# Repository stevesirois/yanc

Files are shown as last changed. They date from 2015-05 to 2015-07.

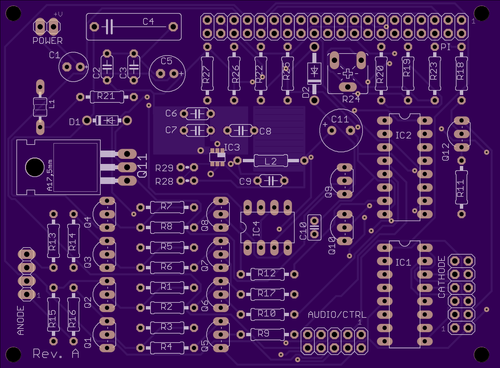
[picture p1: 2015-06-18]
eagle-stuffs/nixie-driver.png

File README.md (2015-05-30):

# YANC
Y.A.N.C. - Yet Another Nixie Clock

This project is the software part of a larger project that include nixie tube clock with no physical controls but only "web" access.

The physical construction will be publish on Instructables (http://www.instructables.com/)

The project is two parts:

Physical part - Nixie Clock

- 4 nixie tubes (IN-14) display
- Raspberry PI Model A+ (256MB) for main controller
- Custom nixie driver circuit and audio ouput (PCB)
- MP3 Playback for alarm
- Sound activated display (extented life of tubes)

Software part - Clock control and remote app

- Controler daemon for clock hardware control (Python)
- REST Server to interact with external world (look mom, no button!)
- IOS App to "talk" to the clock (Swift)

Simply put, this clock will look great, will sync itself on the Net and get it's alarms from my Google Calendar! :-)

More details coming...

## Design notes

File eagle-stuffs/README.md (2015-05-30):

# Eagle 7.2 files
The .sch and .brd files are Eagle CAD schematic and PCB design files.

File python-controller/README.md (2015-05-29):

# Raspberry PI Controller

Python server controlling display, audio & REST server

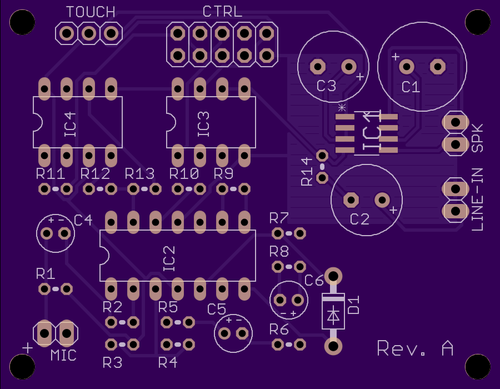
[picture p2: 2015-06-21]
eagle-stuffs/audio.png

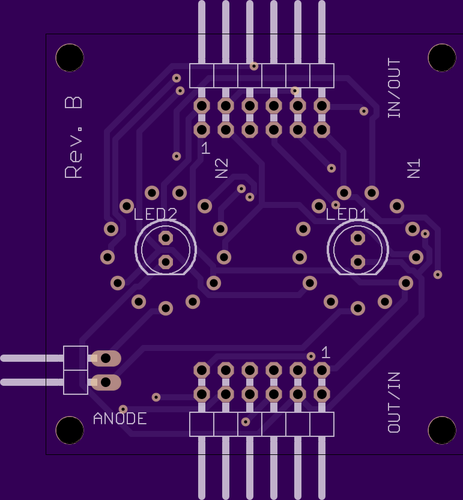
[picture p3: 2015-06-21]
eagle-stuffs/lamp_board_simple.png

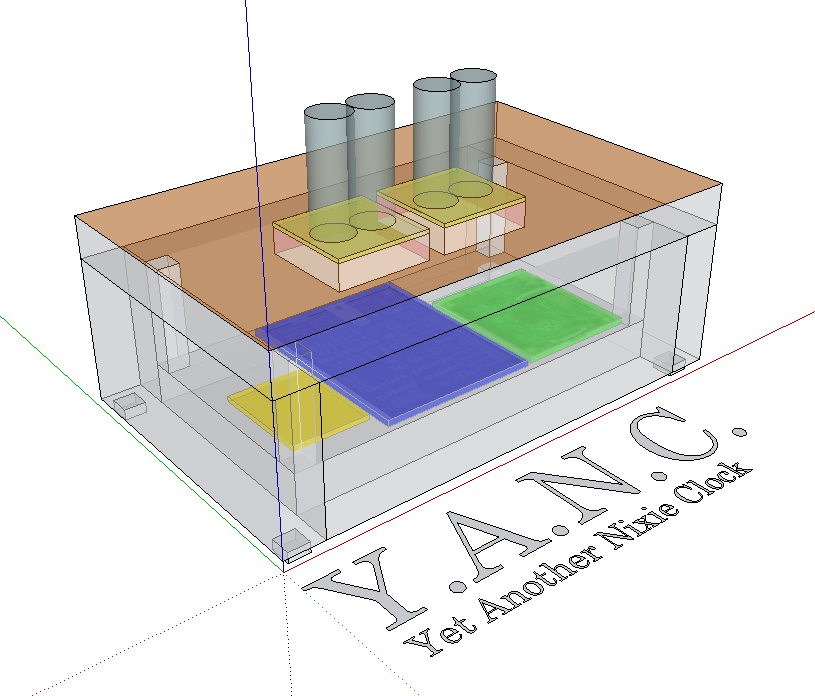
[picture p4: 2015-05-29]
Sketchup-3D/Snapshot.png

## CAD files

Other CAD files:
Sketchup-3D/Nixie clock-full.skp

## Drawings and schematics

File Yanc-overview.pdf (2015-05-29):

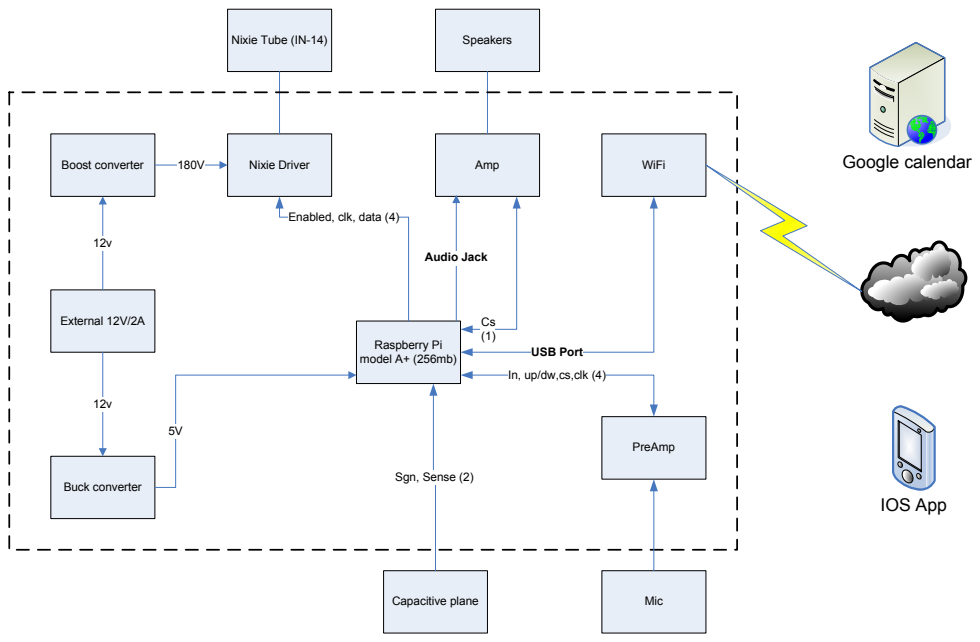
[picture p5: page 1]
Raspberry Pi model A+ (256mb); Boost converter; Nixie Driver; External 12V/2A; Capacitive plane; Sgn, Sense (2); WiFi; USB Port; Amp; Speakers; Audio Jack; Buck converter; Google calendar; Mic; PreAmp; IOS App

Nixie Tube (IN-14)

Enabled, clk, data (4)

In, up/dw,cs,clk (4)

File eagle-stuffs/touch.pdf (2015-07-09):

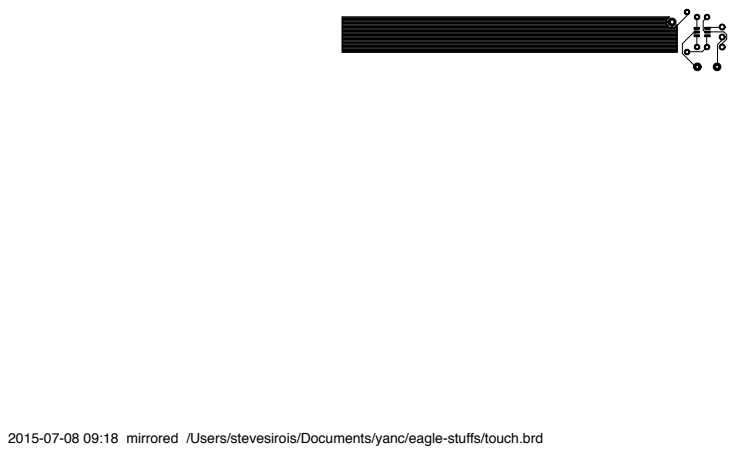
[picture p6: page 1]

2015-07-08 09:18 mirrored /Users/stevesirois/Documents/yanc/eagle-stuffs/touch.brd

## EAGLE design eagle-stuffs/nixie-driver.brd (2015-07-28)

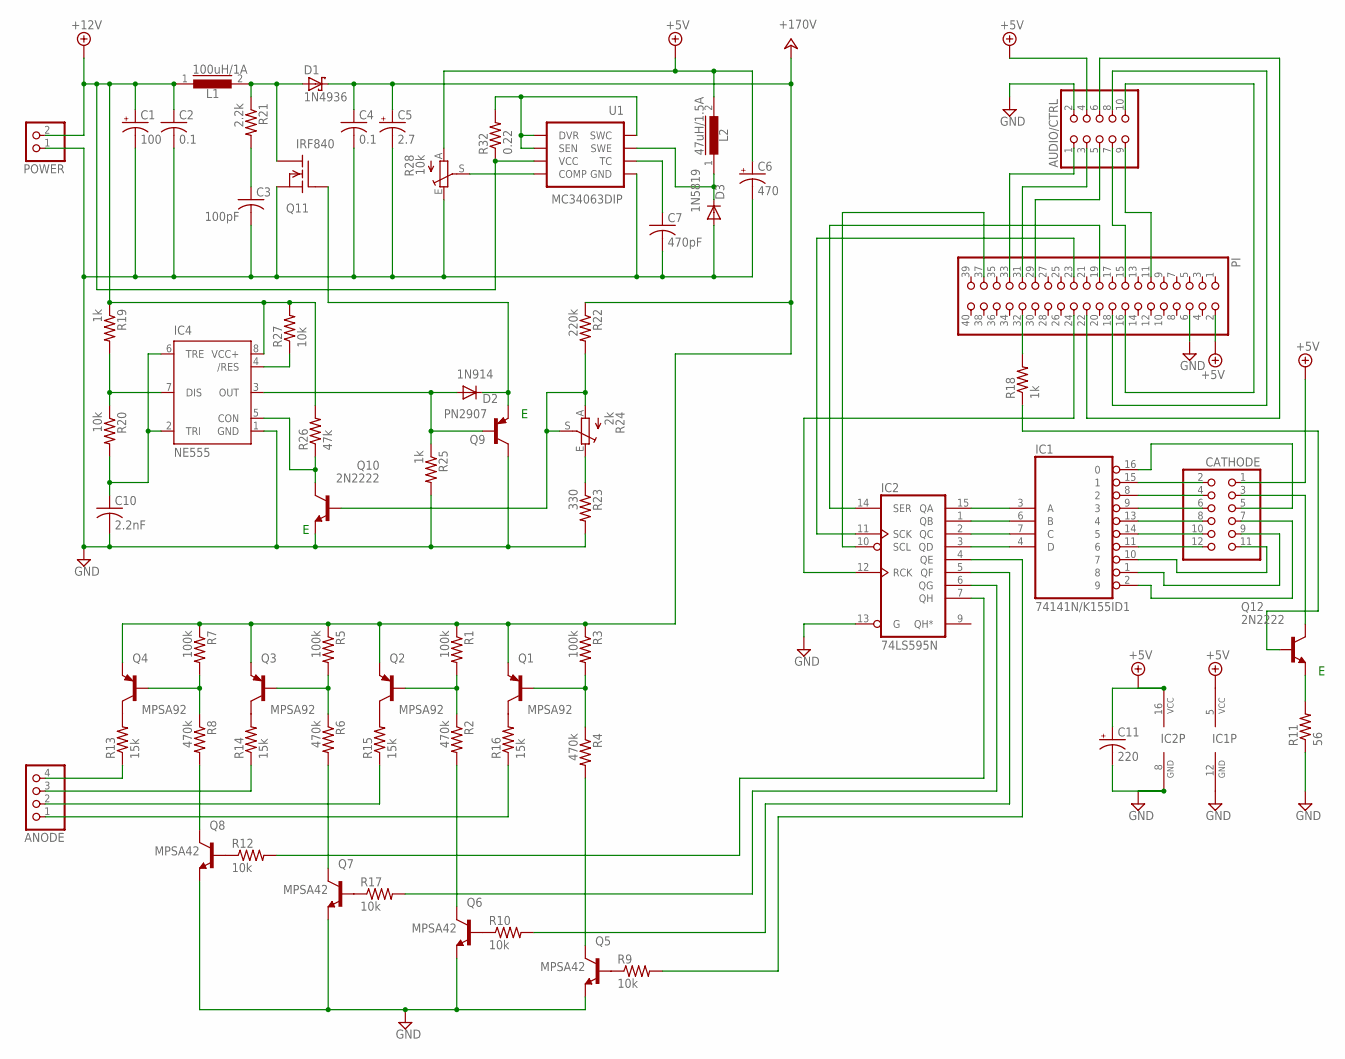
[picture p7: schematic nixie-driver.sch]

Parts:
ANODE: PINHD-1X4; 1X04
AUDIO/CTRL: PINHD-2X5; 2X05
C1: 100; E2,5-6E
C2: 0.1; C050-024X044
C3: 100pF; C050-024X044
C4: 0.1; C150-054X183
C5: 2.7; E2,5-7
C6: 470; E3,5-8
C7: 470pF; C050-024X044
C10: 2.2nF; C025-025X050
C11: 220; E3,5-8
CATHODE: PINHD-2X6; 2X06
D1: 1N4936; DO41-7.6
D2: 1N914; DO41-10
D3: 1N5819; DO41-10
IC1: 74141N/K155ID1; DIL16
IC2: 74LS595N; DIL16
IC4: NE555; DIL-08
L1: 100uH/1A; MMICC7
L2: 47uH/1.5A; MMICC7
PI: PINHD-2X20; 2X20
POWER: PINHD-1X2; 1X02
Q1, Q2, Q3, Q4: MPSA92; TO92-EBC
Q5, Q6, Q7, Q8: MPSA42; TO92-EBC
Q9: PN2907; TO92-CBE
Q10, Q12: 2N2222; TO92-EBC
Q11: IRF840; TO220
R1, R3, R5, R7: 100k; 0207/10
R2, R4, R6, R8: 470k; 0207/10
R9, R10, R12, R17, R20, R27: 10k; 0207/10
R11: 56; 0207/10
R13, R14, R15, R16: 15k; 0207/10
R18, R19, R25: 1k; 0207/10
R21: 2.2k; 0207/10
R22: 220k; 0207/10
R23: 330; 0207/10
R24: 2k; CA6V
R26: 47k; 0207/10
R28: 10k; CA6V
R32: 0.22; 0204V
U1: MC34063DIP; DIP-08

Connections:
+5V: AUDIO/CTRL.4, C6.+, C11.+, CATHODE.1, IC1.5 (VCC), IC2.16 (VCC), L2.2, PI.2, R28.A
+12V: C1.+, C2.1, IC4.8 (VCC+), L1.1, POWER.2, R19.1, R26.2, R27.2, R32.1, U1.6 (VCC)
+24V: C4.1, C5.+, D1.C, Q1.E, Q2.E, Q3.E, Q4.E, R1.1, R3.1, R5.1, R7.1, R22.1
GND: AUDIO/CTRL.2, C1.-, C2.2, C3.2, C4.2, C5.-, C6.-, C7.2, C10.2, C11.-, D3.A, IC1.12 (GND), IC2.8 (GND), IC2.13 (G), IC4.1 (GND), PI.6, POWER.1, Q5.E, Q6.E, Q7.E, Q8.E, Q9.C, Q10.E, Q11.3 (S), R11.1, R23.2, R25.2, R28.E, U1.4 (GND)
unnamed: D1.A, L1.2, Q11.2 (D), R21.1
unnamed: CATHODE.2, IC1.15 (1)
unnamed: CATHODE.4, IC1.8 (2)
unnamed: CATHODE.6, IC1.9 (3)
unnamed: CATHODE.8, IC1.13 (4)
unnamed: CATHODE.10, IC1.14 (5)
unnamed: CATHODE.12, IC1.11 (6)
unnamed: CATHODE.11, IC1.10 (7)
unnamed: CATHODE.9, IC1.1 (8)
unnamed: CATHODE.7, IC1.2 (9)
unnamed: CATHODE.5, IC1.16 (0)
unnamed: IC1.3 (A), IC2.15 (QA)
unnamed: IC1.6 (B), IC2.1 (QB)
unnamed: IC1.7 (C), IC2.2 (QC)
unnamed: IC1.4 (D), IC2.3 (QD)
unnamed: PI.32, R18.2
unnamed: Q4.B, R7.2, R8.1
unnamed: Q3.B, R5.2, R6.1
unnamed: Q2.B, R1.2, R2.1
unnamed: Q1.B, R3.2, R4.1
unnamed: Q4.C, R13.2
unnamed: Q3.C, R14.2
unnamed: Q2.C, R15.2
unnamed: Q1.C, R16.2
unnamed: ANODE.4, R13.1
unnamed: ANODE.3, R14.1
unnamed: ANODE.2, R15.1
unnamed: ANODE.1, R16.1
unnamed: Q8.C, R8.2
unnamed: Q8.B, R12.1
unnamed: Q7.B, R17.1
unnamed: Q6.B, R10.1
unnamed: Q5.B, R9.1
unnamed: Q7.C, R6.2
unnamed: Q6.C, R2.2
unnamed: Q5.C, R4.2
unnamed: IC2.7 (QH), R12.2
unnamed: IC2.6 (QG), R17.2
unnamed: IC2.5 (QF), R10.2
unnamed: IC2.4 (QE), R9.2
unnamed: IC2.12 (RCK), PI.24
unnamed: IC2.11 (SCK), PI.23
unnamed: IC2.14 (SER), PI.19
unnamed: Q12.E, R11.2
unnamed: CATHODE.3, Q12.C
unnamed: Q12.B, R18.1
unnamed: AUDIO/CTRL.1, PI.33
unnamed: AUDIO/CTRL.3, PI.31
unnamed: AUDIO/CTRL.5, PI.29
unnamed: AUDIO/CTRL.7, PI.15
unnamed: AUDIO/CTRL.9, PI.11
unnamed: IC4.7 (DIS), R19.2, R20.1
unnamed: AUDIO/CTRL.10, PI.16
unnamed: AUDIO/CTRL.8, PI.18
unnamed: AUDIO/CTRL.6, PI.22
unnamed: C3.1, R21.2
unnamed: R32.2, U1.1 (SWC), U1.7 (SEN), U1.8 (DVR)
unnamed: IC4.4 (/RES), R27.1
unnamed: D2.A, IC4.3 (OUT), Q9.B, R25.1
unnamed: IC4.5 (CON), Q10.C, R26.1
unnamed: R28.S, U1.5 (COMP)
unnamed: D2.C, Q9.E, Q11.1 (G)
unnamed: IC2.10 (SCL), PI.37
unnamed: Q10.B, R22.2, R24.A, R24.S
unnamed: R23.1, R24.E
unnamed: C10.1, IC4.2 (TRI), IC4.6 (TRE), R20.2
unnamed: C7.1, U1.3 (TC)
unnamed: D3.C, L2.1, U1.2 (SWE)

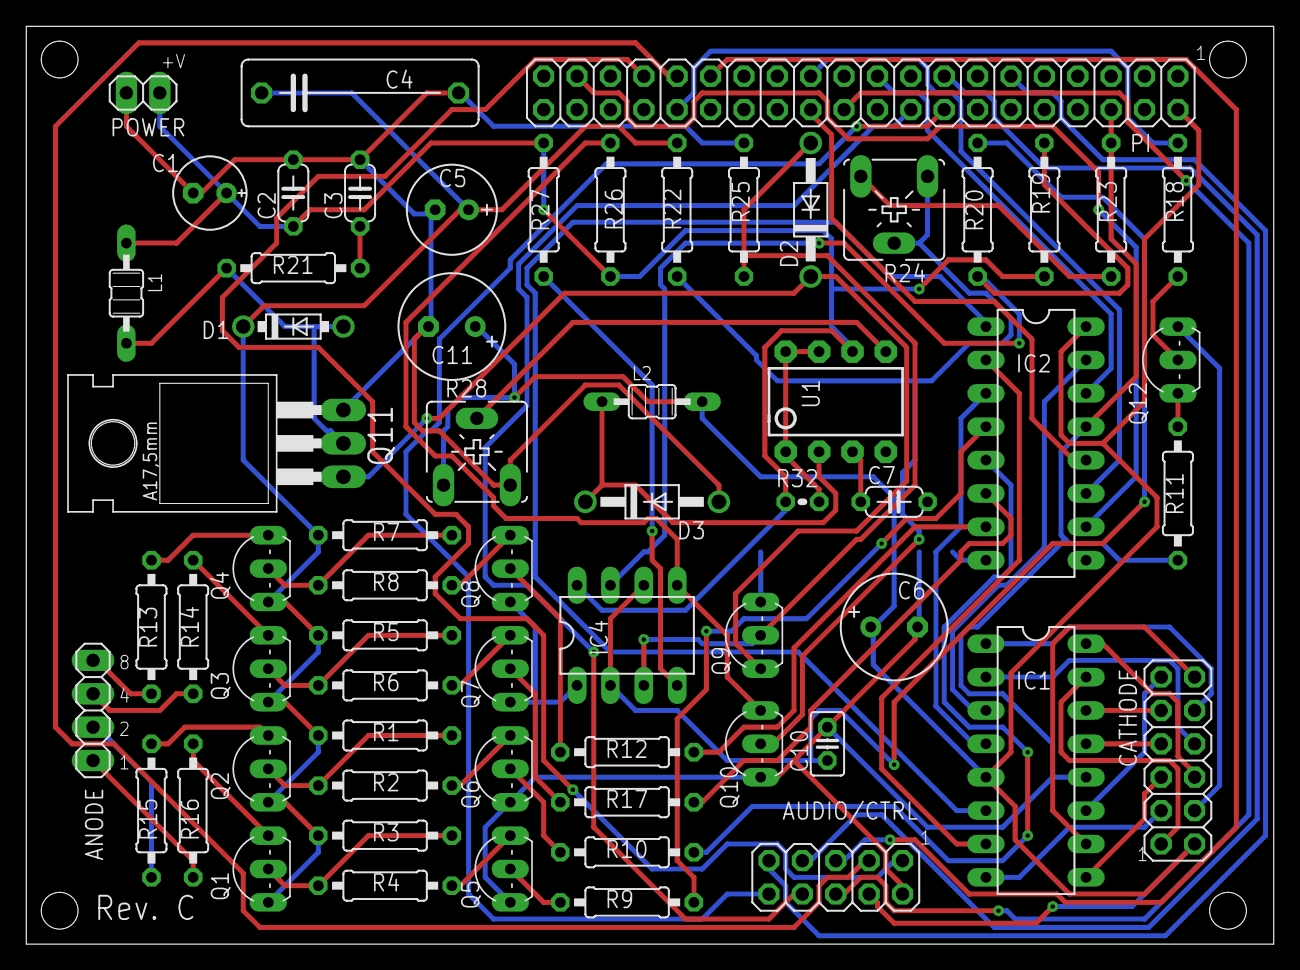
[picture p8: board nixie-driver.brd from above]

Board: 2 copper layers, 94.9 x 69.8 mm, 64 parts (0 on the bottom side), 72 nets.

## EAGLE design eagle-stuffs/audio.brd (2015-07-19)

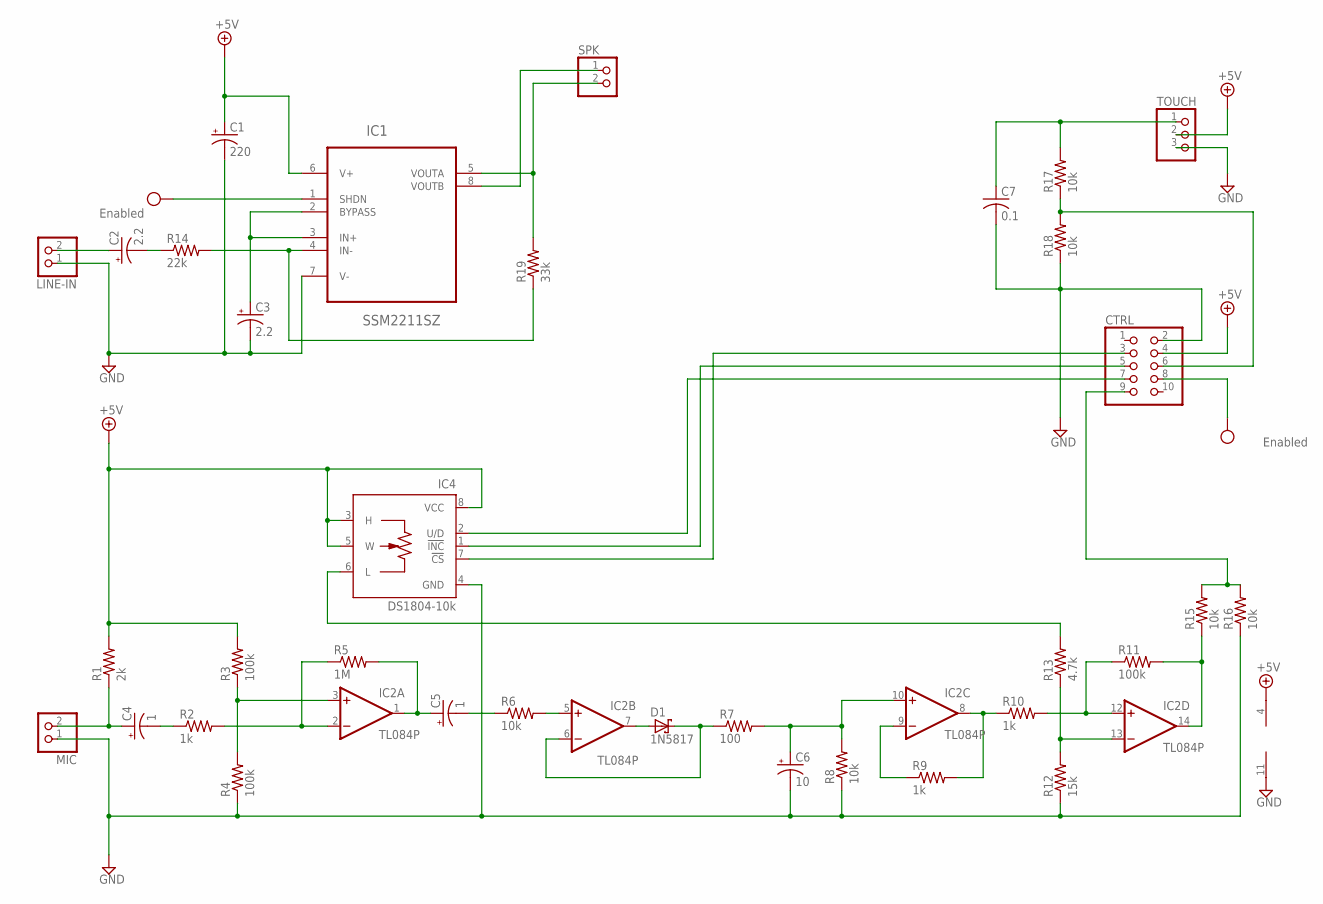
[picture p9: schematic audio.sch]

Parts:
C1: 220; E3,5-10
C2, C3: 2.2; E3,5-8
C4, C5: 1; E2-4
C6: 10; E2-4
C7: 0.1; C025-024X044
CTRL: PINHD-2X5; 2X05
D1: 1N5817; DO41-7
IC1: SSM2211SZ; SOIC127P600X175-8N
IC2: TL084P; DIL14
IC4: DS1804-10k; DIL08
LINE-IN: PINHD-1X2; 1X02
MIC: PINHD-1X2; 1X02
R1: 2k; 0204V
R2, R9, R10: 1k; 0204V
R3, R4, R11: 100k; 0204V
R5: 1M; 0204V
R6, R8, R15, R16, R17, R18: 10k; 0204V
R7: 100; 0204V
R12: 15k; 0204V
R13: 4.7k; 0204V
R14: 22k; 0204V
R19: 33k; 0204V
SPK: PINHD-1X2; 1X02
TOUCH: PINHD-1X3; 1X03

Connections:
+5V: C1.+, CTRL.4, IC1.6 (V+), IC2.4 (V+), IC4.3 (H), IC4.5 (W), IC4.8 (VCC), R1.2, R3.2, TOUCH.2
GND: C1.-, C3.-, C6.-, C7.2, CTRL.2, IC1.7 (V-), IC2.11 (V-), IC4.4 (GND), LINE-IN.1, MIC.1, R4.1, R8.1, R12.1, R16.1, R18.1, TOUCH.3
unnamed: IC1.5 (VOUTA), R19.2, SPK.2
unnamed: C2.+, LINE-IN.2
unnamed: C2.-, R14.1
unnamed: IC1.4 (IN-), R14.2, R19.1
unnamed: C3.+, IC1.2 (BYPASS), IC1.3 (IN+)
unnamed: IC1.8 (VOUTB), SPK.1
unnamed: IC4.6 (L), R13.2
unnamed: C4.-, R2.1
unnamed: C4.+, MIC.2, R1.1
unnamed: IC2.2 (-IN), R2.2, R5.1
unnamed: C5.+, IC2.1 (OUT), R5.2
unnamed: C5.-, R6.1
unnamed: IC2.14 (OUT), R11.2, R15.1
unnamed: IC2.3 (+IN), R3.1, R4.2
unnamed: CTRL.9, R15.2, R16.2
unnamed: D1.A, IC2.7 (OUT)
unnamed: IC2.5 (+IN), R6.2
unnamed: CTRL.3, IC4.7 (!CS)
unnamed: CTRL.5, IC4.1 (!INC)
unnamed: CTRL.7, IC4.2 (U/D)
unnamed: D1.C, IC2.6 (-IN), R7.1
unnamed: C6.+, IC2.10 (+IN), R7.2, R8.2
unnamed: IC2.9 (-IN), R9.1
unnamed: IC2.8 (OUT), R9.2, R10.1
unnamed: IC2.12 (+IN), R10.2, R11.1
unnamed: C7.1, R17.2, TOUCH.1
unnamed: IC2.13 (-IN), R12.2, R13.1
unnamed: CTRL.6, R17.1, R18.2
VCC: CTRL.8, IC1.1 (SHDN)

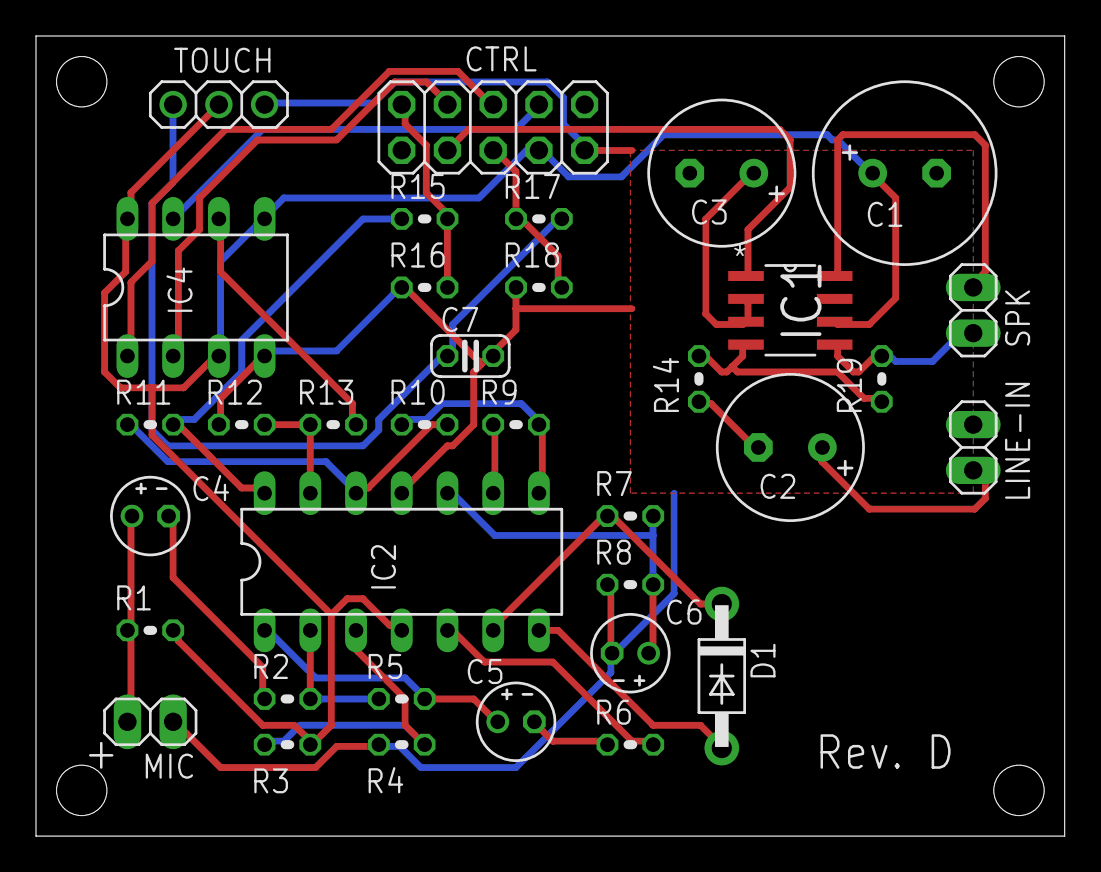
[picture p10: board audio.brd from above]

Board: 2 copper layers, 57.1 x 44.5 mm, 35 parts (0 on the bottom side), 31 nets.

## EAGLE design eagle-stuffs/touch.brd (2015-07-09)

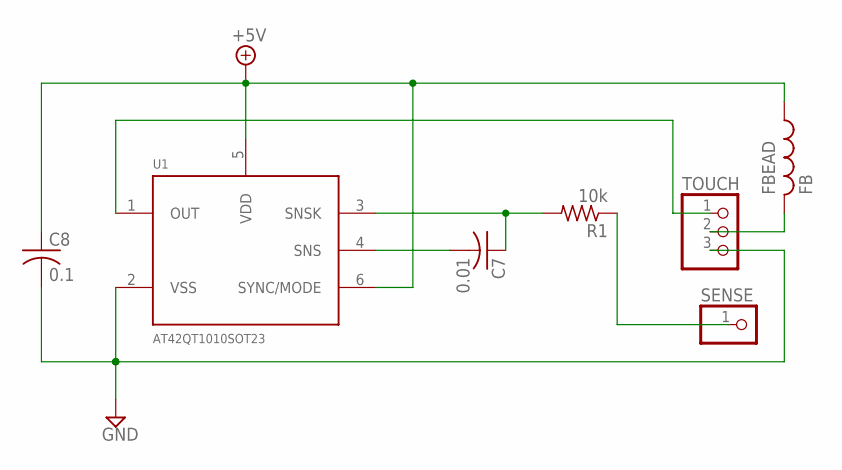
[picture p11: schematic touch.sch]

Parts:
C7: 0.01; C025-025X050
C8: 0.1; C025-025X050
FBEAD: FB
R1: 10k; 0207/10
SENSE: PINHD-1X1; 1X01
TOUCH: PINHD-1X3; 1X03
U1: AT42QT1010SOT23; SOT23-6

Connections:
+5V: C8.1, FBEAD.P$1 (1), U1.5 (VDD), U1.6 (SYNC/MODE)
GND: C8.2, TOUCH.3, U1.2 (VSS)
unnamed: TOUCH.1, U1.1 (OUT)
unnamed: R1.1, SENSE.1
unnamed: FBEAD.P$2 (2), TOUCH.2
unnamed: C7.1, R1.2, U1.3 (SNSK)
unnamed: C7.2, U1.4 (SNS)

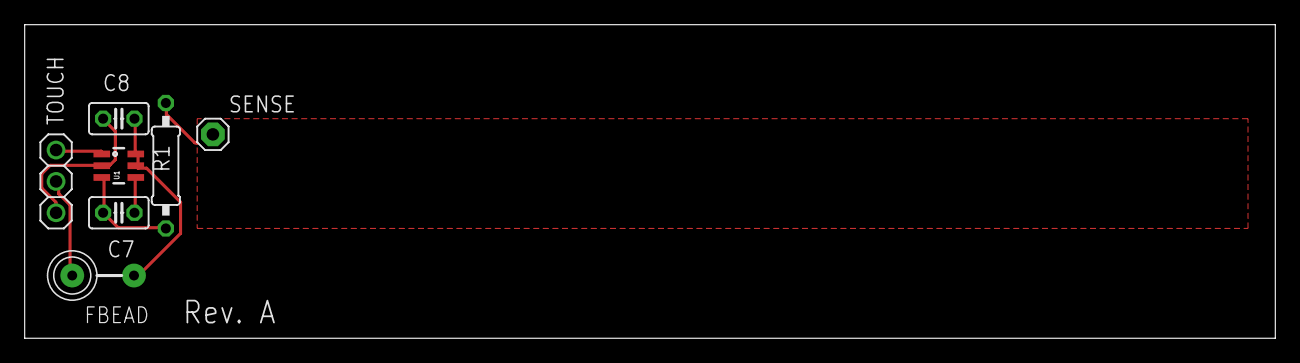
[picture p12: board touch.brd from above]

Board: 2 copper layers, 101.3 x 25.4 mm, 7 parts (0 on the bottom side), 7 nets.

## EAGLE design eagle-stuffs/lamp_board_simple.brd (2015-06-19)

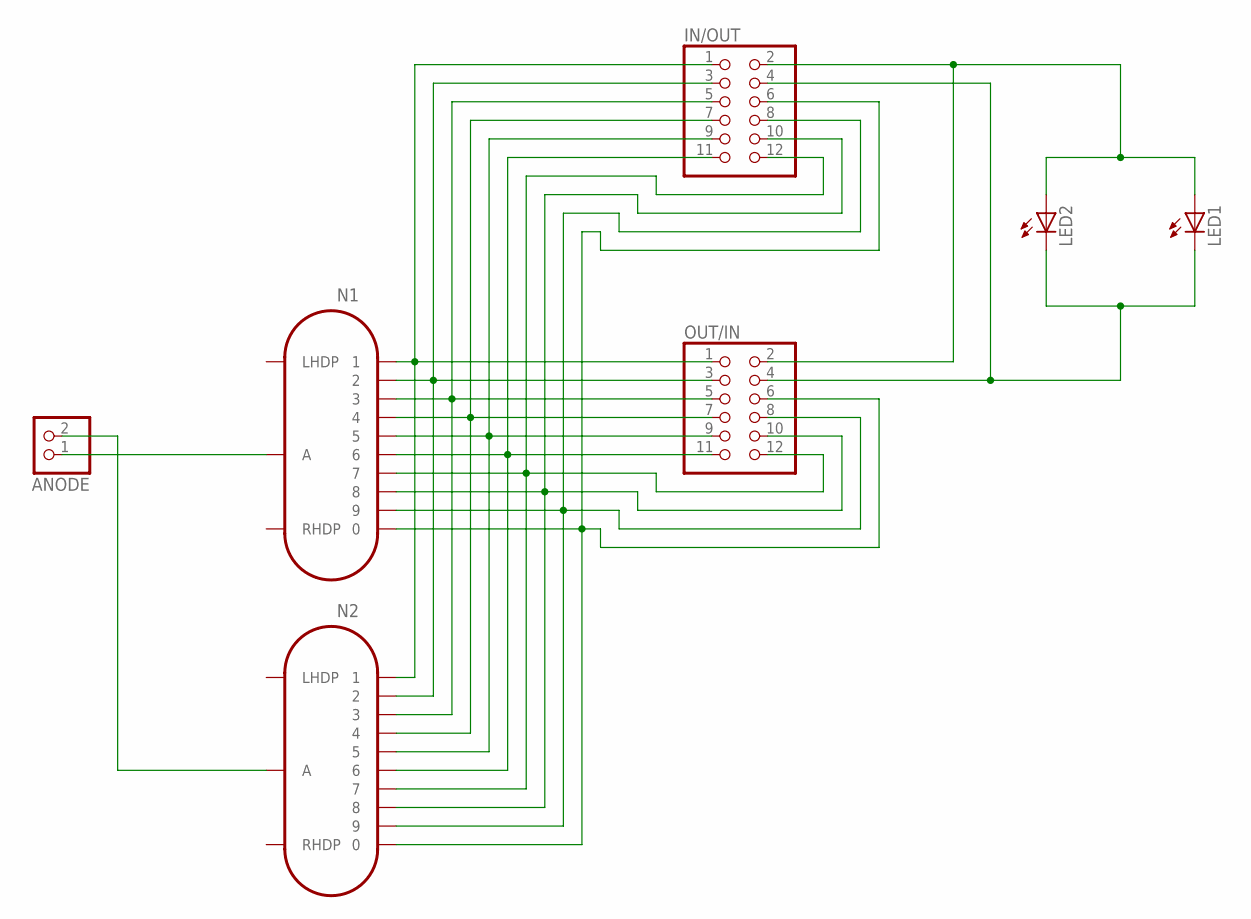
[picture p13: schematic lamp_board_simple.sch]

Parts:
ANODE: PINHD-1X2/90; 1X02/90
IN/OUT: PINHD-2X6/90; 2X06/90
LED1, LED2: LED5MM
N1, N2: IN-14
OUT/IN: PINHD-2X6/90; 2X06/90

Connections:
unnamed: ANODE.1, N1.A
unnamed: ANODE.2, N2.A
unnamed: IN/OUT.4, LED1.K (C), LED2.K (C), OUT/IN.4
unnamed: IN/OUT.2, LED1.A, LED2.A, OUT/IN.2
unnamed: IN/OUT.1, N1.1, N2.1, OUT/IN.1
unnamed: IN/OUT.3, N1.2, N2.2, OUT/IN.3
unnamed: IN/OUT.5, N1.3, N2.3, OUT/IN.5
unnamed: IN/OUT.7, N1.4, N2.4, OUT/IN.7
unnamed: IN/OUT.9, N1.5, N2.5, OUT/IN.9
unnamed: IN/OUT.11, N1.6, N2.6, OUT/IN.11
unnamed: IN/OUT.12, N1.7, N2.7, OUT/IN.12
unnamed: IN/OUT.10, N1.8, N2.8, OUT/IN.10
unnamed: IN/OUT.8, N1.9, N2.9, OUT/IN.8
unnamed: IN/OUT.6, N1.0, N2.0, OUT/IN.6

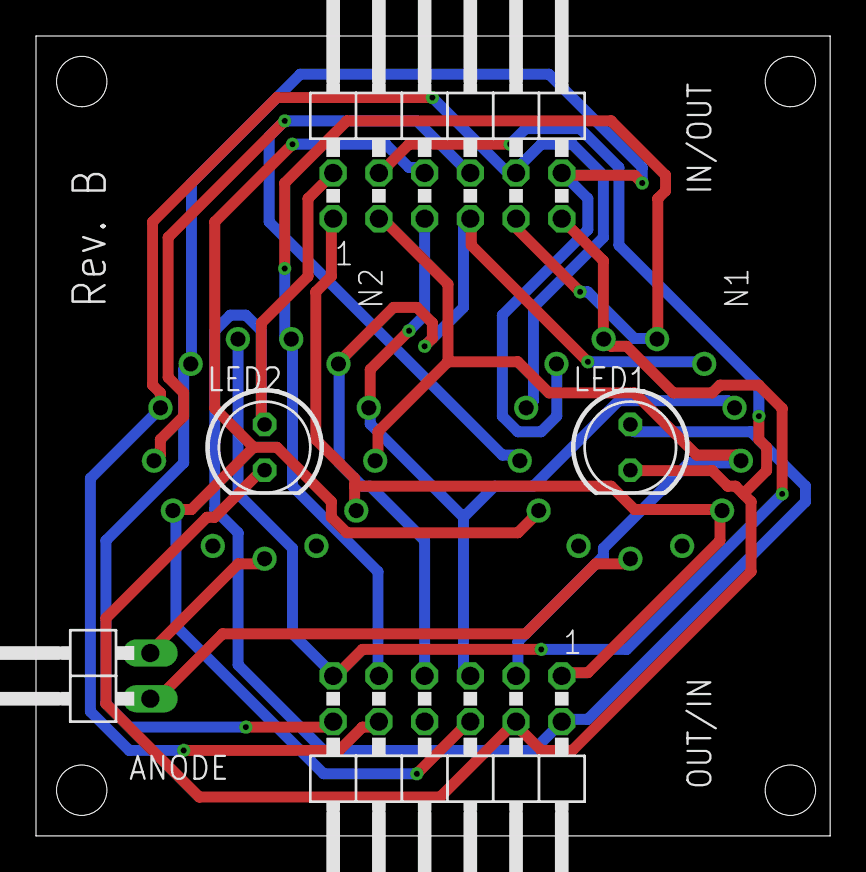
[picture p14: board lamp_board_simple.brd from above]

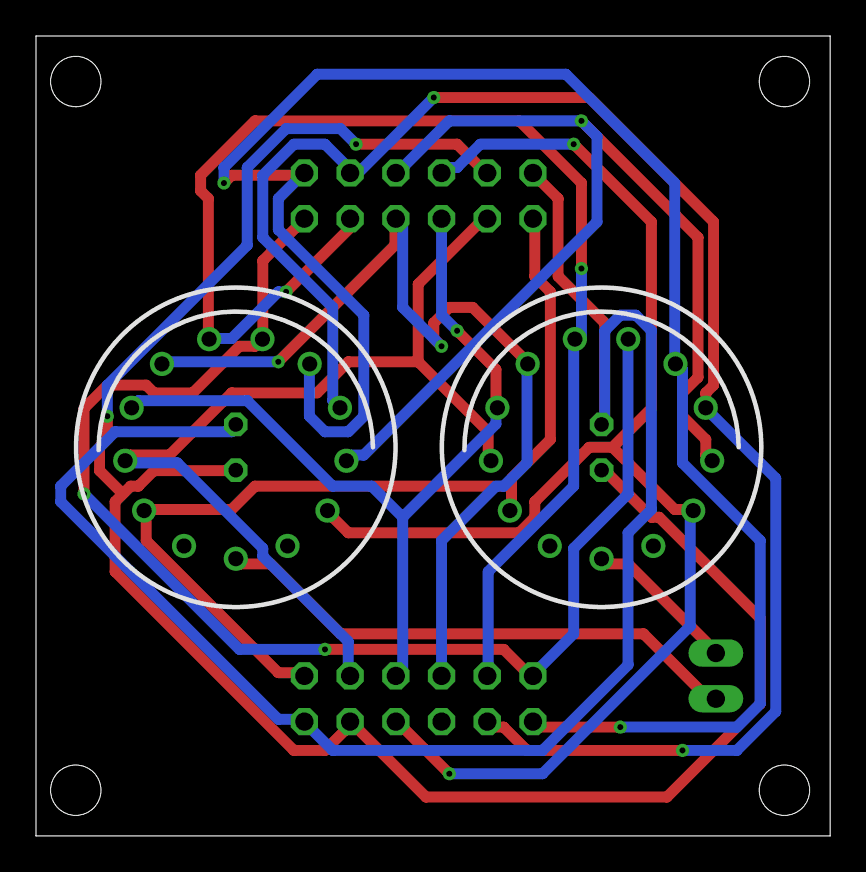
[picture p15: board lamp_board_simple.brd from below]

Board: 2 copper layers, 44.1 x 44.4 mm, 7 parts (2 on the bottom side), 14 nets.

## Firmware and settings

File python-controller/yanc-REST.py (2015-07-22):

import datetime
import os
import httplib2
import json
import oauth2client
import sqlite3 as sqlite
import socket
import sys

from flask import Flask, request, Response
from oauth2client.client import SignedJwtAssertionCredentials
from apiclient import discovery

# Load private info into JSON Object - SHOULD BE IN SAME DIR AS THIS FILE
with open(os.path.join(os.path.dirname(os.path.realpath(__file__)),
        'private_info.json')) as data_file:
    myprivateinfo = json.load(data_file)

# ******************************************************************************
def get_credentials():
    
    service_account_email = myprivateinfo['service_account_email']

    # Open P12 key file containing private key
    """Note for the PI : PKCS12 format is not supported by the PyCrypto library. 
    Need to convert to PEM : 
    => openssl pkcs12 -in xxxxx.p12 -nodes -nocerts > xxxxx.pem
    Password => notasecret
    This is no big deal since the password is knowed from the whole planet! 
    BUT... keep the file safe, it's YOUR private key! :-)
    """
    with open(myprivateinfo['private_key_file']) as f:
        private_key = f.read()

    # Set credentials for the calendar.readonly API scope
    # This is a "two-legged OAuth" (2LO) scenario
    credentials = SignedJwtAssertionCredentials(service_account_email, 
        private_key, 'https://www.googleapis.com/auth/calendar.readonly')
    
    return credentials

def get_next_event():

    credentials = get_credentials()
    http = credentials.authorize(httplib2.Http())
    service = discovery.build('calendar', 'v3', http=http)

    # My Nixie Clock Calendar ID
    calendarId = myprivateinfo['calendarId']

    now = datetime.datetime.utcnow().isoformat() + 'Z' # 'Z' indicates UTC time
    
    eventsResult = service.events().list(
        calendarId=calendarId, timeMin=now, maxResults=10, singleEvents=True,
        orderBy='startTime').execute()
    
    # Only interested in the list of events on the calendar
    events = eventsResult.get('items', [])
    
    # Only get "start" info, that's all I need
    out = []
    if not events:
        out.append('nil')
    for event in events:
        out.append(event['start'].get('dateTime', event['start'].get('date')))
    
    return json.JSONEncoder(indent=4, separators=(',', ': ')).encode(out)

# ******************************************************************************
app = Flask(__name__)
app_name = 'yanc' 
app_version = 'v1.0'

@app.route('/'+app_name+'/api/'+app_version+'/next-alarm')
def next_alarm():
    return get_next_event()

@app.route('/'+app_name+'/api/'+app_version+'/led-brightness', 
    methods=['PUT', 'GET'])
def led_brightness():
    if request.method == 'PUT':
        data = request.json
        
        conn = None

        try:
            # Persistant data store setup
            conn = sqlite.connect(myprivateinfo['database'])
            c = conn.cursor()
            # Make shure security on database file AND IT'S FOLDER are writable
            #   be the accound running the server (ex.: www-data).
            #   Lost an 1 hour on this one after transfering to uWSGI server.
            #   All you will get is this stupid message : 
            #       "unable to open database file"
            #   BUT, the conn object is ok, only at the execute of the update
            #   this msg appear!!
            c.execute("UPDATE PARAMS SET PVALUE = ? WHERE PNAME='led-brightness'", 
                (data['value'],)) #Carefull, single element tuple need trailing coma
            print >>sys.stderr, 'execute ok'
            conn.commit()
            conn.close()
        except sqlite.Error, e:
            print >>sys.stderr, 'Error in PUT "%s"' % e.args[0]

        finally:
            if conn:
                conn.close()   

        # Speak to yanc!
        # Create a UDS socket
        sock = socket.socket(socket.AF_UNIX, socket.SOCK_STREAM)
        server_address = '/tmp/uds_socket'

        try:
            sock.connect(server_address)
        except socket.error, msg:
            print >>sys.stderr, msg
            sys.exit(1)

        try:
            # Send data
            message = data['value']
            #print >>sys.stderr, 'sending "%s"' % message
            sock.sendall(message)

            amount_received = 0
            amount_expected = len(message)
            
            while amount_received < amount_expected:
                data = sock.recv(16)
                amount_received += len(data)

        finally:
            #print >>sys.stderr, 'closing socket'
            sock.close()

        return 'OK'  
    else:
        data = []

        conn = None

        try:        
            conn = sqlite.connect(myprivateinfo['database'])
            c = conn.cursor()
            c.execute("SELECT * FROM PARAMS WHERE PNAME='led-brightness'")
            param_exist = c.fetchone()
            if param_exist:
                data.append(param_exist[1])
    
        except sqlite.Error, e:
            print >>sys.stderr, 'Error in GET "%s"' % e.args[0]

        finally:
            if conn:
                conn.close()   

        js = json.JSONEncoder(indent=4, separators=(',', ': ')).encode(data)

        resp = Response(js, status=200, mimetype='application/json')
        return resp

if __name__ == '__main__':
    app.run(port=5000, debug=True, host='0.0.0.0', use_reloader=True)

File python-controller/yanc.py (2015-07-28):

#!/usr/bin/env python
# *********************************************************************
# Y.A.N.C. - Yet Another Nixie Clock
#
# Author    : Steve Sirois
# Version   : A
# Date      : 2015-05-26
#
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
import spidev
import RPi.GPIO as GPIO
import time
import os
import sys
import stat
import socket
import sqlite3
import daemon
import signal
import logging 
import logging.handlers 
from lockfile.pidlockfile import PIDLockFile
import select
import requests
import json
import sqlite3 as sqlite
import dateutil.parser
from dateutil.tz import tzlocal
import datetime
from enum import Enum
import multiprocessing
from multiprocessing import Process, Queue
from Queue import Empty
from subprocess import call

#import pygame  
#   Lack good support for MP3 playback so used Music Player Daemon

# **************************************************************************
# Contants section, know what you do :-)
#
# Setup IO (PP = Physical Pin, (l) = Denote an active state on low)
# Nixie Board
OUT_SRCLR = 26  # PP 37 - SCL [SRCLR] (l) pin on 74LS595 - 0 = clear, 1 = enable
OUT_LED = 12    # PP 32 - Ambient led driver - will be PWM driven
# Digital potentiometer
OUT_UP_DOWN = 22    # PP 15(7) - U/D(l) on DS1804
OUT_INC = 5         # PP 29(5) - INC(h) on DS1804
OUT_CS_MICRO = 13   # PP 31(3) - CS(l) on DS1804 for microphone sensitivity
# Audio enabled
OUT_AUDIO = 24      # PP 18(8) - AUDIO ENABLED on SSM2211
# Inputs
IN_NOISE_DETECT = 17    # PP 11(9) - Output of OpAmp TL084
IN_TOUCH_DETECT = 25    # PP 22(6) - Atmel AT42QT1011 QTouch Capacitive 
# Socket server for communication with uWSGI REST Server (yanc-REST)
SERVER_ADDRESS = '/tmp/uds_socket'
# PID & Log
PIDFILE = '/var/run/yanc-daemon.pid'
LOGFILE = '/var/log/yanc-daemon.log'
WORKING_DIR = '/home/pi/yanc'
# Timing
REFRESH_RATE = 70       # Hz

CYCLE_MAIN_WAIT = 15    # Sec.
CYCLE_MUSIC_WAIT = 0.5  # Sec.

REFRESH_ALARMS = 3600   # Sec.
CHECK_ALARM = 60        # Sec.
SNOOZE_DELAY = 300      # Sec.
TURN_OFF_NIXIE = 10     # Sec.

# **************************************************************************
# Set logging level here
logger = logging.getLogger("yanc") 
logger.setLevel(logging.DEBUG) # DEBUG - INFO - WARNING - ERROR - CRITICAL

fh = logging.FileHandler(LOGFILE)
fh.setLevel(logging.DEBUG)

formatter = logging.Formatter("%(asctime)s - %(levelname)s - %(message)s") 
fh.setFormatter(formatter) 
logger.addHandler(fh)

# **************************************************************************
# Load private info into JSON Object - SHOULD BE IN SAME DIR AS THIS FILE
with open(os.path.join(os.path.dirname(os.path.realpath(__file__)),
        'private_info.json')) as data_file:
    myprivateinfo = json.load(data_file)

# **************************************************************************
# Enum
Message = Enum('Message', 
    'alarm quit play unpause stop touch sound hold time off')
State = Enum('State', 
    'sleeping alarm snooze')

def callback_noise():
    #logger.debug('somebody yell at me!!!')
    pass

def callback_touch():
    logger.debug('somebody touch me!!!')
    q_music.put(Message.touch)
    q_display.put(Message.touch)

def sensor_detect(q_sensor):
    qdata = None
    state_t = GPIO.input(IN_TOUCH_DETECT)
    state_n = GPIO.input(IN_NOISE_DETECT)

    while True:
        try:
            qdata = q_sensor.get_nowait()
        except Empty:  # queue was empty, better chance next time
            pass

        if qdata == Message.quit:
            break
        
        state_now = GPIO.input(IN_TOUCH_DETECT)

        if state_now and state_t:
            pass    #no change
        elif state_now == True and state_t == False:
            # detect only rising transition
            state_t = state_now
            callback_touch()
        else:
            state_t = state_now

        state_now = GPIO.input(IN_NOISE_DETECT)

        if state_now and state_n:
            pass    #no change
        elif state_now == True and state_n == False:
            # detect only rising transition
            state_n = state_now
            callback_noise()
        else:
            state_n = state_now

        # Ok, don't get to crazy about reading those sensors!!!
        time.sleep(0.05)

    logger.info('sensors is done.')

def initIO():
    # Setup I/O
    GPIO.setwarnings(False)
    GPIO.setmode(GPIO.BCM)

    # OUTPUT
    GPIO.setup(OUT_SRCLR, GPIO.OUT, initial=GPIO.LOW) 
    GPIO.setup(OUT_LED, GPIO.OUT, initial=GPIO.LOW)
    GPIO.setup(OUT_UP_DOWN, GPIO.OUT, initial=GPIO.LOW) 
    GPIO.setup(OUT_INC, GPIO.OUT, initial=GPIO.LOW)
    # De-select microphone
    GPIO.setup(OUT_CS_MICRO, GPIO.OUT, initial=GPIO.HIGH)   
    # Turn off sound for now
    GPIO.setup(OUT_AUDIO, GPIO.OUT, initial=GPIO.HIGH)      

    # INPUT (no pullup or pulldown resistor required here)
    GPIO.setup(IN_NOISE_DETECT, GPIO.IN)
    GPIO.setup(IN_TOUCH_DETECT, GPIO.IN) 
    
    # Attach callback... NOT!!!
    #   As version 0.5.11 of RPi.GPIO lib, those threaded callback work fine in
    #   a single process app. But when I run this in my multiprocess app,
    #   GPIO detect multiple rising edge event instead of one?!?
    #   So, had to implement my own loop to check pin input status.
    #GPIO.add_event_detect(IN_NOISE_DETECT, GPIO.FALLING, callback=callbackX)  
    #GPIO.add_event_detect(IN_TOUCH_DETECT, GPIO.RISING, callback=callbackY)  

def adjust_gain(incr, direction):
    usleep = lambda x: time.sleep(x / 1000000.0)
    GPIO.output(OUT_CS_MICRO, GPIO.LOW)

    if direction == 'UP':
        GPIO.output(OUT_UP_DOWN, GPIO.HIGH)    
    else:
        GPIO.output(OUT_UP_DOWN, GPIO.LOW)    

    for x in range(incr):
        GPIO.output(OUT_INC, GPIO.HIGH) 
        usleep(1000)
        GPIO.output(OUT_INC, GPIO.LOW)    
        usleep(1000)

    GPIO.output(OUT_CS_MICRO, GPIO.HIGH)

def show_led(q_led):

    led = GPIO.PWM(OUT_LED, 70) # 70 Hz refresh
    qdata = None

    while True:
        try:
            qdata = q_led.get_nowait()
        except Empty:  # queue was empty, better chance next time
            pass
        else:
            logger.debug('q_led received : {0}'.format(qdata))

        if qdata == Message.quit:
            break

        if qdata >= 0.0:
            led.start(qdata)

        qdata = None

    led.start(0)
    logger.info('show_led is done.')
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

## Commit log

2015-05-29 Initiale creation
    [lamp_board_simple.brd, lamp_board_simple.sch, nixie-driver.brd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]
2015-05-30 Start to frame the thing
2015-05-30 Add beta audio
    [audio.brd, audio.sch]
2015-05-31 Working on audio board
    [audio.brd, audio.sch]
2015-06-01 Still working on audio…
    [audio.brd, audio.sch]
2015-06-01 Found SSM2211 lib… still going
    [audio.brd, audio.sch]
2015-06-01 This should work…
    [audio.brd, audio.sch]
2015-06-02 Waiting for proto board test design
    [audio.brd, audio.sch]
2015-06-02 Final beta
    [audio.brd, audio.sch]
2015-06-02 Capacitive board
    [touch.brd, touch.sch]
2015-06-09 Updated something
    [nixie-driver.brd, nixie-driver.sch, touch.sch]
2015-06-11 Minor stuffs
    [audio.brd, audio.sch]
2015-06-17 Layout adjustement
    Adjusted some physical component size & layout
    [nixie-driver.brd, nixie-driver.sch]
2015-06-18 Add revision info
    [lamp_board_simple.brd]
2015-06-18 Mirror cathod connector
    Corrected major layout error!!! Needed to mirror cathod connector since
    it mounted on bottom layer on lamp board and not on this board. Blowed
    up my Pi this morning for the maiden test of the board :-(
    [nixie-driver.brd, nixie-driver.sch]
2015-06-18 Ajustements to silk
    [lamp_board_simple.brd, lamp_board_simple.sch, nixie-driver.brd]
2015-06-18 Minor ajustements
    [lamp_board_simple.brd, lamp_board_simple.sch, nixie-driver.sch]
2015-06-18 Changed some drilling size
    [audio.brd, touch.brd, touch.sch]
2015-06-19 Corrected mirror pinout on nixie
    [lamp_board_simple.brd, lamp_board_simple.sch]
2015-06-19 Updated to rev. b
    [nixie-driver.brd, nixie-driver.sch]
2015-06-19 Added some info
    [audio.brd, lamp_board_simple.brd, lamp_board_simple.sch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]
2015-06-21 Final version
    [audio.brd, audio.sch]
2015-06-21 C1 value changed
    [audio.brd, audio.sch]
2015-06-21 Added some more info
    [audio.sch]
2015-07-06 adjusted value of digital pot
    [audio.brd, audio.sch]
2015-07-06 Corrected pin assignment and some cleanup
    [yanc.py]
2015-07-07 Move back led-brightness() at is place!
    Doing too much cleanup…
    [yanc.py]
2015-07-09 Added voltage divider on output
    I forgot I was dealing with 3.3v input chip! :-(
    [audio.brd, audio.sch]
2015-07-09 Remove bottom side - now single-sided pcb
    [touch.brd]
2015-07-15 Discarded the TPS562209
    Too sensitive to touch (touching the chip, blow-it up!
    [nixie-driver.brd, nixie-driver.sch]
2015-07-15 Removed second digital pot
    [audio.brd, audio.sch]
2015-07-15 Inverted input on follower section for mic
    [audio.brd, audio.sch]
2015-07-17 Ajusted layout + add backplane shield
    [nixie-driver.brd, nixie-driver.sch]
2015-07-19 Change R13 value
    Going at 10k on the digit pot will have the reverse effect on gain and
    shutdown the mic.
    [audio.brd, audio.sch]
2015-07-24 Added sensors functions
2015-07-28 Change fixed resistors for voltage output ajust. to pot.
    The PI seems to be quite touchy about the voltage drop under load. Got
    to push it to 5.1v to make the red led stop to blink!
    [nixie-driver.brd, nixie-driver.sch]

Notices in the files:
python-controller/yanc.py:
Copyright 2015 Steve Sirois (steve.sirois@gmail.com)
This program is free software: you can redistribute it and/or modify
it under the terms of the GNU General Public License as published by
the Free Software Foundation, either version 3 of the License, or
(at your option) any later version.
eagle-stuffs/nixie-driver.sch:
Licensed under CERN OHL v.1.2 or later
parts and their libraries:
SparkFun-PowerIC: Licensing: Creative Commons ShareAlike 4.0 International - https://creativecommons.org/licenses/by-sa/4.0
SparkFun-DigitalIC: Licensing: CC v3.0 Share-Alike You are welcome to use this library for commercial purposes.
